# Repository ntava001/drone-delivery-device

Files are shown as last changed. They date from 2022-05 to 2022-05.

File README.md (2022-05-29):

# Drone Delivery Device

A drone delivery device able to obtain and distribute a package for the consumer

## Introduction
One of the biggest problems with a drone delivery system is maneuverability around a crowded residential area. Currently, drones need to land in an open area, but that can be problematic in less spacious areas. Most residences have obstacles such as trees, power lines, and light posts that can impede the drone’s ability to land. Thus, my team and I's design solution for this problem is to build an 18 foot tall system that clears most obstacles, safely catching a package dropped by a hovering drone, without the drone landing, and to transporting the package to a more accessible area for the consumer to pick up.

The Virtual and Physical Prototype of our design operate roughly the same way. The virtual prototype is used to show how our design would look like using a full scale model. It illustrates the design of the device with respect to a house, includes the padding used to catch the package as well as the sensor that detects it. The physical model is very scaled down and dictates how our device will operate in real life. The physical prototype looks more at the electrical components used to drive the motor, allowing us to create the intended design.

## Prototype Demonstrations 

### SolidWorks Prototype

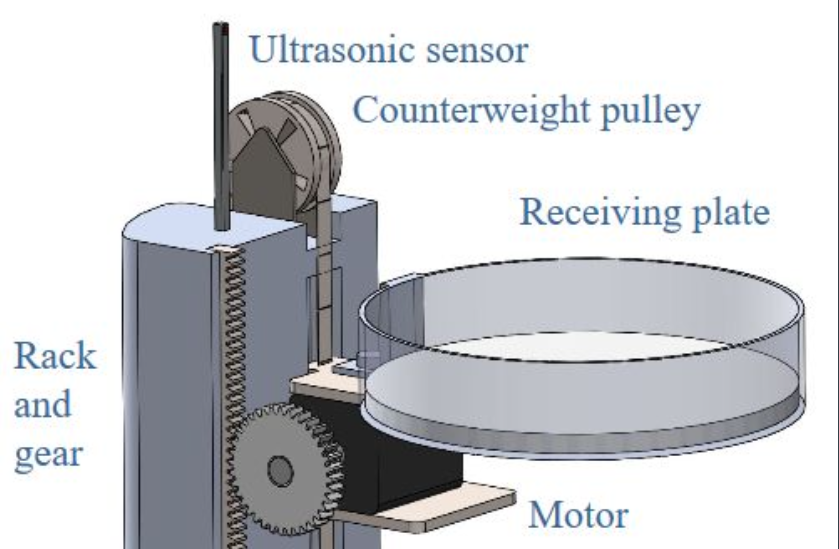
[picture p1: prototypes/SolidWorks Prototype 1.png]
SolidWorks1


### Physical Prototype

Physical1

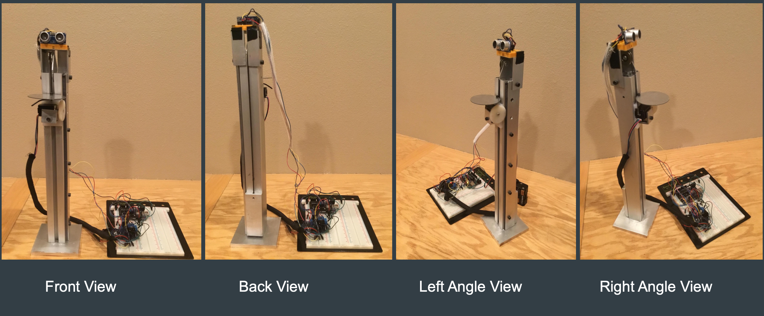
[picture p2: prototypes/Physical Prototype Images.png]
Physical2


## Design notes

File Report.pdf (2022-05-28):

## Team D4S-2 Ara Petrosyan Jason Chan Navid Tavakoulnia Oscar Jauregui

# University of California, Riverside Department of Mechanical Engineering

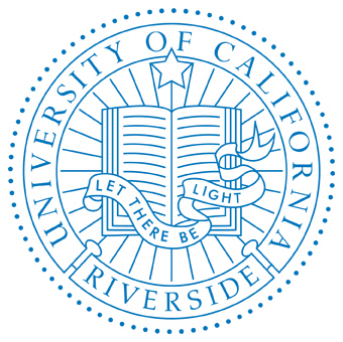
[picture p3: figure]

Executive Summary

With researching and developing a drone delivery system, there are certain limitations and restrictions it

must overcome. One of the biggest problems with a drone delivery system is maneuverability around a crowded

residential area. Currently, drones need to land in an open area, but that can be problematic in less spacious

areas. Most residences have obstacles such as trees, power lines, and light posts that can impede the drone’s

ability to land. Thus, our design solution for this problem is to build an 18 foot tall system that clears most

obstacles, safely catching a package dropped by a hovering drone, without the drone landing, and to

transporting the package to a more accessible area for the consumer to pick up.

Our design solution is to create a receiving platform run by a motor. The theoretical idea for our solution

is to catch the package as it is free falling by accelerating the receiving platform downwards to closely match

the velocity of the falling package. Because of the similar velocities, the package landing on the platform will

impart a very minimal average force due to impulse momentum theory, thus, greatly reducing the chance of any

damage on the package. The key features of our proposed designs include an ultrasonic sensor that will detect

the package, a rack and pinion, a counterweight, the receiving platform with dampening foam, and a T-slotted

frame that will vertically guide the movement of the counterweight and receiving platform.

To evaluate the success or failure of our design solution, we modeled a virtual design using SolidWorks

as well as built and machined a physical prototype. In SolidWorks, we were able to fully simulate real-world

conditions such as the weather, environment, and mechanical properties of materials. In our SolidWorks

simulation, we designed a drone to deliver and drop a package, and our design solution was able to function as

we intended to without any problems. For our physical prototype, we simplified many mechanisms to simply

show a “proof of concept.” We used an Arduino and a stepper motor to simulate the controls aspect of the

design. Common problems that occurred include gear slippage, friction, lack of motor power, and delay in the

sensor. Recommendations for improving this design can stem from better materials, better coding for the

Arduino, a dedicated power supply, and the use of a photo sensor or laser instead of an ultrasonic sensor to

remove the delay in detecting the package.

Table of Contents

1. Introduction -------------------------------------------------------------------------------------------------------------3
2. Problem Statement --------------------------------------------------------------------------------------------------3-4
3. Design Solution --------------------------------------------------------------------------------------------------------4

3.1 Conceptual Design to Detailed Design ----------------------------------------------------------------------4-6

3.2 Design Description ------------------------------------------------------------------------------------------------6

3.3 Functions of Key Features -------------------------------------------------------------------------------------6-7

3.4 Overview of Design----------- ------------------------------------------------------------------------------------7

3.5 Constraints and Assumptions ------------------------------------------------------------------------------------8

3.6 Physical Prototype Design -----------------------------------------------------------------------------------8-10

4. Modeling and Analysis ----------------------------------------------------------------------------------------------11

4.1 Statics -------------------------------------------------------------------------------------------------------------11

4.2 Kinematics and Dynamics -------------------------------------------------------------------------------------12

4.3 Impact Analysis --------------------------------------------------------------------------------------------------12

4.4 Motor Power Requirements ------------------------------------------------------------------------------------13

4.5 Vibration Analysis -----------------------------------------------------------------------------------------------14

5. Approach to Solution ------------------------------------------------------------------------------------------------14

5.1 Morphological Chart --------------------------------------------------------------------------------------------14

5.2 Early Conceptual Designs ----------------------------------------------------------------------------------15-17

5.3 Decision Matrices -------------------------------------------------------------------------------------------18-19

6. Discussion of Results ------------------------------------------------------------------------------------------------20

6.1 Test Procedures and Results -----------------------------------------------------------------------------------21

References -------------------------------------------------------------------------------------------------------22

Appendix ------------------------------------------------------------------------------------------------------23-24

### 1. Introduction

On December 1st, 2016, Jeff Bezos, CEO of Amazon reveals on CBS’ 60 Minutes the idea of using a fleet of

drones to quickly deliver packages to consumers. Ever since Bezos’ public announcement of developing a drone

delivery service, other logistics services and companies decided to do the same. Companies and services such as

United States Postal Service (USPS), FedEx, DHL, UPS, and even 7-Eleven are researching and developing

their own drone deliveries to keep up with technology, and more specifically, Amazon. This new concept

revolves around the idea of utilizing drone technology to transport packages to customers and stands as a

primary inspiration for our project. Many challenges, however, are certain to rise from this method of delivery.

Thus, these challenges stand as a motivation for our intended project. One of the challenges is the means of

properly accepting the delivery upon the arrival. Thus, our problem statement is the means of making a device

that can properly accept packages dropped in free fall from drones. The intended customers for this device are

regular online delivery users who own residential property. This report will begin by presenting the devised

design solution followed by an analysis demonstrating its plausibility, and providing the approach undertaken

for the solution.

### 2. Problem Statement

The drone based delivery system along with basic facts regarding homes in the United States has influenced our

problem definition. The nature of the drone based delivery involves an active drone that would maneuver

around a home to provide delivery. Most homes however, have trees, light posts, gutters, possible power lines

and other obstacles that can potentially be hazardous to the drone itself as it will presumably have to maneuver

around it. The lower the drone would have to go down to the landing spot, the more obstacles it will presumably

encounter. Thus, to provide efficiency, it is best for the drone to remain at higher elevations relative to the

property. Furthermore, environmental factors such as high winds can influence this system. Thus, our problem

definition is to make a device that can receive the package dropped by a drone from a height of 18 feet from

ground level, protect it from theft and environmental factors, and transport it to an intended location for the recipient under the conditions of a maximum wind speed of 5 mph and a drone horizontal velocity of within

2mph.

### 3. Design Solution

### 3.1 Conceptual Design to Detailed Design

The “Top Down Approach” was implemented to break down the main function of our design to several

sub functions. The main functions of our designs consist of the ability to catch a falling load, absorb the impact,

and transport it to a location for pick up. The sub functions for the design include opening of the flaps of the

receiving plate, lifting and lowering of the receiving plate, rotation of pulleys, and providing a light post for

aesthetics. The chosen conceptual design to accomplish these mechanisms is shown in Figure 1.

Figure #1 Conceptual Design of Motor Powered Receiving Tower

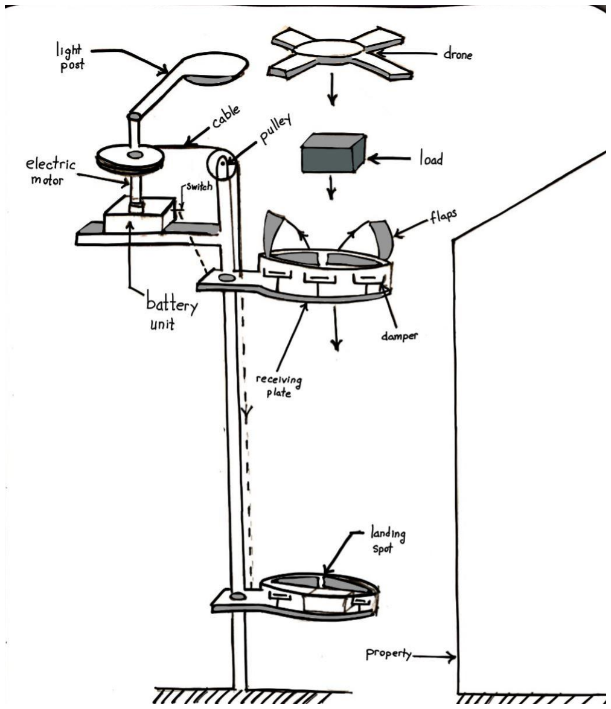
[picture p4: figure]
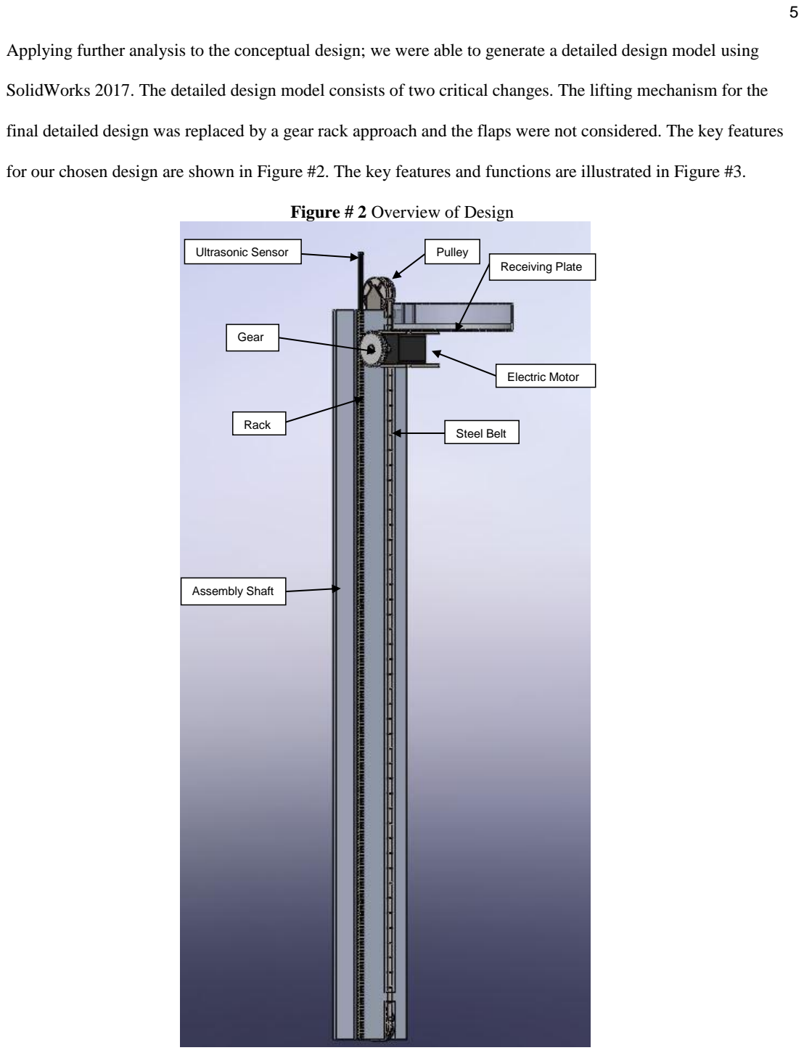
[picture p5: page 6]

Applying further analysis to the conceptual design; we were able to generate a detailed design model using

SolidWorks 2017. The detailed design model consists of two critical changes. The lifting mechanism for the

final detailed design was replaced by a gear rack approach and the flaps were not considered. The key features

for our chosen design are shown in Figure #2. The key features and functions are illustrated in Figure #3.

Figure # 2 Overview of Design

Receiving Plate

Rack

Pulley

Steel Belt

Gear

Ultrasonic Sensor

Assembly Shaft

Electric Motor

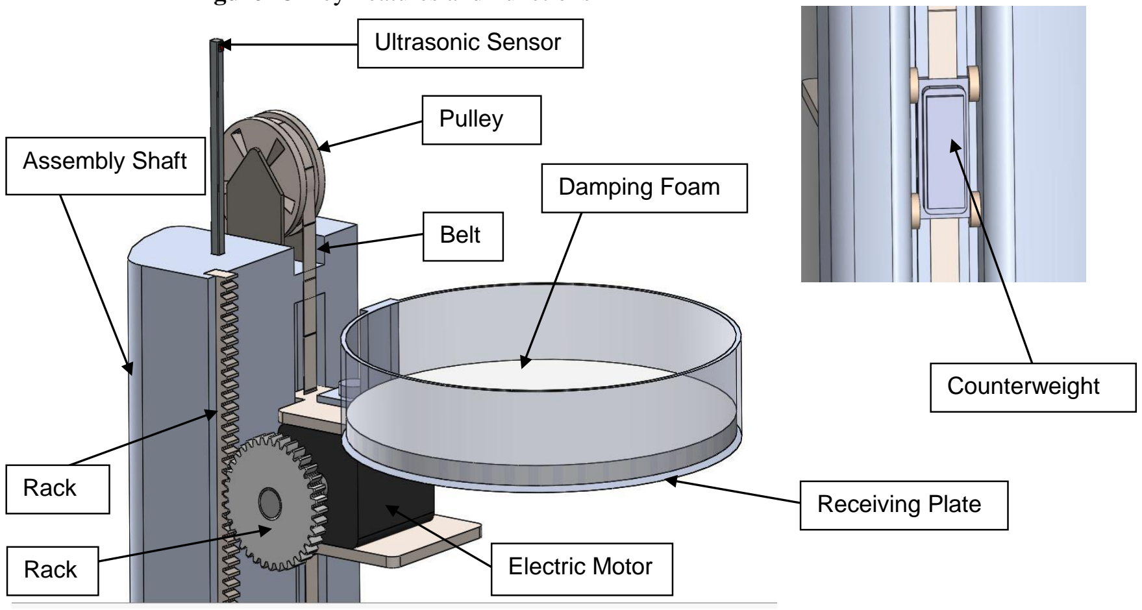
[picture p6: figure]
Pulley; Rack; Assembly Shaft; Ultrasonic Sensor; Damping Foam; Belt; Electric Motor; Receiving Plate; Counterweight

### 3.2 Design Description

As mentioned before, drone deliveries require clearance space from obstacles. Therefore our chosen design

resembles an 18 feet tower shaft. The primary function of our chosen design is to provide a lifting and lowering

mechanism. The receiving plate rides along the main assembly shaft. This feature, as will be described stands

crucial to receiving, protecting, and transporting a package dropped by a drone down to an intended location.

### 3.3 Functions of Key Features

Our chosen design consists of nine main features, each of which has specific function. The ten primary features

include the gear, rack, electric motor, receiving plate, damping foam, continuous belt, an ultrasonic sensor,

pulley and of course the main assembly shaft. The electric motor provides power to the gear which in turn rides

along the rack. Thus, the torque provided by the electric motor allows, the main receiving plate to move up or

down the main assembly shaft. A counterweight rides along the back of the main assembly shaft. The

counterweight and the receiving plate are supported by a continuous belt along top and bottom pulleys. The

purpose of the counterweight is to match the weight of the receiving plate and electric motor, thereby keeping

the system in equilibrium. The receiving plate serves as the target location where the package is intended to

Figure #3 Key Features and Functions

land. It is circular with a diameter of 1 meter. The damping foam, shown in white, sits inside the receiving plate

to soften the falling impact. An ultrasonic sensor sits on top of the main assembly. This provides key electrical

inputs to the motor. A critical theme of our design involves catching the falling mass. This is accomplished with

the ultrasonic sensor and the motor. As the mass passes by the ultrasonic sensor, the receiving plate shall

accelerate downward to a location along the shaft that matches the speed of the falling mass upon contact. Once

it is caught, the receiving plate steadily descends downward to deliver the package.

### 3.4 Overview of Design

The environment for which our design must be compatible with is outdoors near an average residential house as

shown in Figure #3. The graphic illustrations help visualize how are chosen concept will actually blend with its

appropriate environment. What a drone delivery will be expected to look like based off of our design upon the

receiving and transporting end is shown in Figure #5 and Figure #6 respectively.

Figure #4 Overview Design with Environment

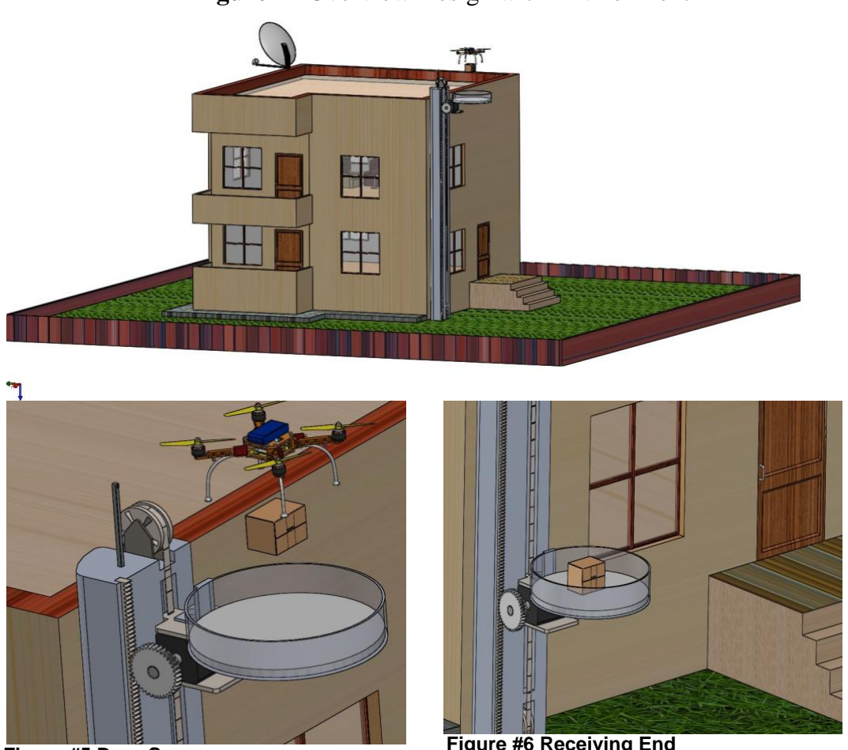
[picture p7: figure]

Figure #5 Drop Scene | Figure #6 Receiving End

### 3.5 Constraints and Assumptions

Several constraints and assumptions are implemented in the design for functionality purposes. The materials

used to construct the components of the device shall be assumed to live up to their physical properties. These

include factors such as the yield and tensile strength. As the drone approaches the target location, it must be at a

maximum height of 5 feet above the center of the receiving plate and have a maximum horizontal velocity of

2.2 mph. Wind conditions may vary, but the maximum allowable wind speed in any arbitrary direction will be

no more than 5 mph. Air resistance within this range shall be designed to be negligible and not affect the

functions of the design. The acceleration due to gravity will be presumed as

With regards to the

load, the minimum weight is constrained to 1 lb with a maximum weight of 50 lbs. Furthermore, the package

dimensions shall not exceed 1 x 1 ft.

### 3.6 Physical Prototype Design

A physical design was machined together to resemble our virtual design. The purpose of a physical prototype is

to create a scaled down representation of the virtual model that can detect the velocity of a falling package and

obtain it with a receiving plate. It is composed of an ultrasonic sensor that is used to detect the falling mass, and

activate a motor to move the object along a rack . The weight of the receiving plate, stepper motor, and slider

are held in place by a counter weight using a pulley system. This allows each of the components to remain

stationary at the top of the assembly shaft when there is no operation taking place. The motor itself is attached

to a gear and held in place by a slider that enables a smooth transition throughout the rack. The rack is attached

to an aluminum strip to keep it immobilized and the receiving plate is pinned to the rod to remain static. We

used a Bipolar motor (20x30mm) operating at 3.9V, since we need a small motor to fit with our rod and one that

can operate with low power.

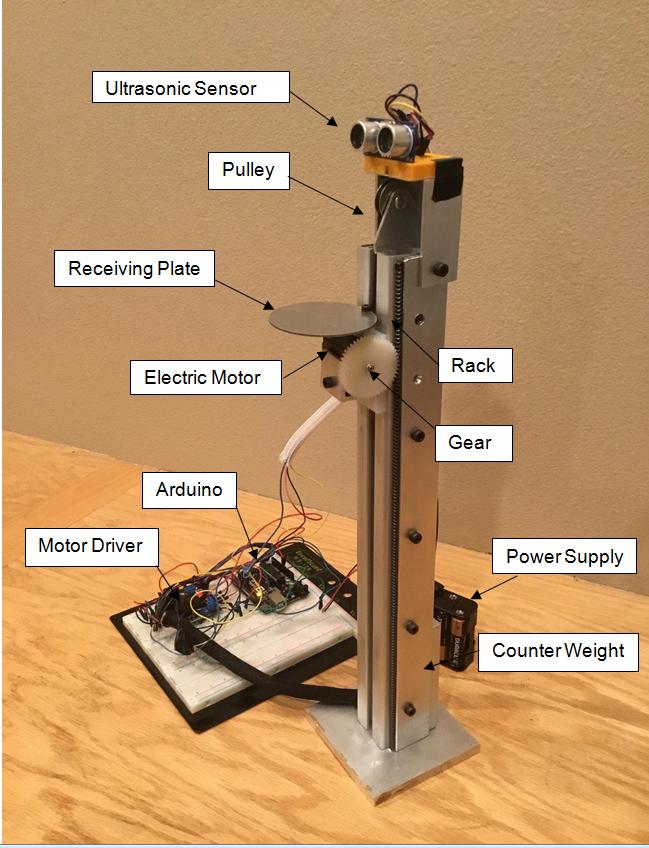
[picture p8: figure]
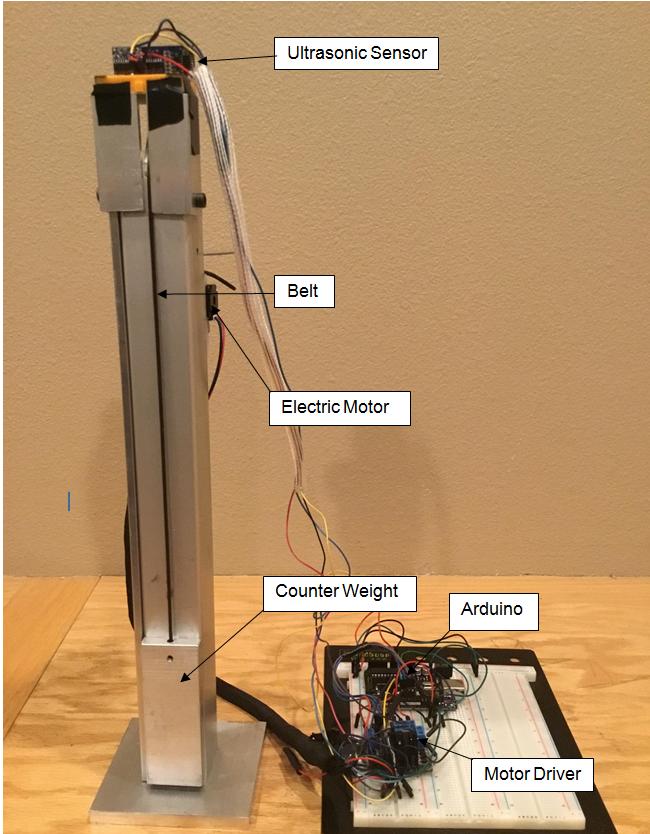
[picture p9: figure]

Figure #7A Physical Prototype-Side View | Figure #7B Physical Prototype- Back View

The electrical components used to operate our motor include an arduino board, motor driver, ultrasonic sensor,

as well as a 9V battery. The code inputted in the arduino allows us to alter the functionality of the motor itself.

We were able manipulate the speed, number of revolutions, direction, as well as the delay time of the motor that

best fits the conditions for our design. The arduino board itself however, provides a low-current control signals

to the motor, so a motor driver is obtained to fix that problem. The motor driver is a little current amplifier

attached to the arduino board to provide higher- current signals that can drive the motor. The ultrasonic sensor

is also attached to the arduino and is the key to starting up all the components. Once the object is detected by

the sensor, the code for the arduino will be read, activating the driver and motor. A 9V battery is attached to the

circuit board as well to provide efficient power to the arduino, ultrasonic sensor, motor driver, and the motor

itself.

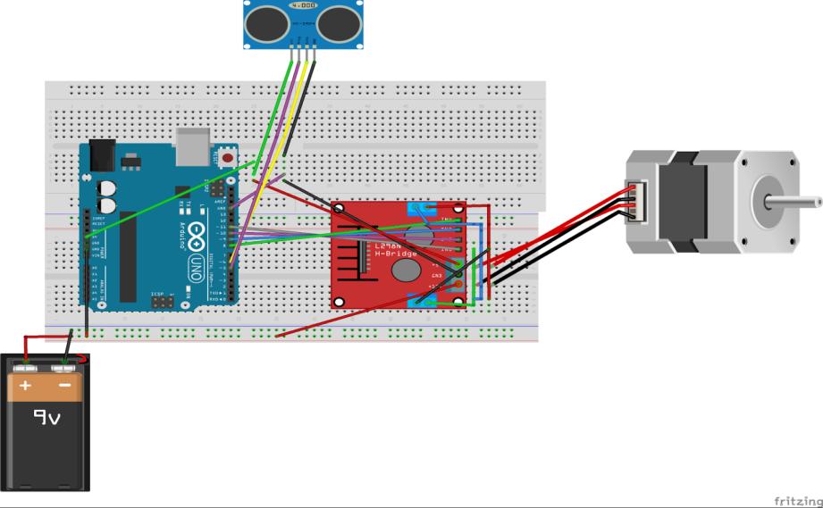
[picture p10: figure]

Figure #9 Electrical Components

The control systems are simplified with the block diagram shown in Figure #9. The load, released by the drone

passes through an ultrasonic sensor. The sensor then sends information related to the package’s velocity at that

instance to the arduino. The arduino then controls the stepper motor by providing it with the necessary steps to

turn in order to match the speed of the falling mass.

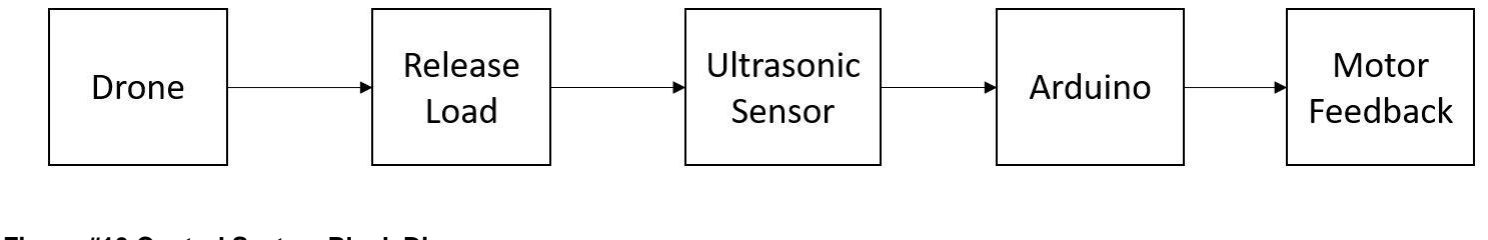
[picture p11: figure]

Figure #10 Control System Block Diagram

### 4. Modeling and Analysis

### 4.1 Statics

Although the chosen motor has enough holding torque, our system must remain in equilibrium at all times such

as in the event of a power outage. A free body diagram for a continuous belt along a two pulley system is shown

below in Figure #9. The sum of moments about point O must be 0 N-m at all times. The weight of our receiving

plate, must therefore, match the counterweight of our assembly. The detailed analysis is shown below.

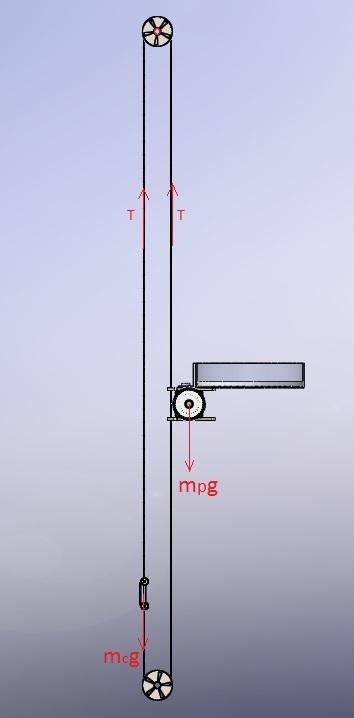
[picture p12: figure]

Figure #9 FBD of pulley system

Estimated Mass of Receiving Plate = 14 lbs (SolidWorks-mass properties)

Tensile Strength of steel cables range from 120-14,000 psi; Thus, with the given weight, steel cables are not expected to yield and the system shall remain in equilibrium at all times.

### 4.2 Kinematics and Dynamics

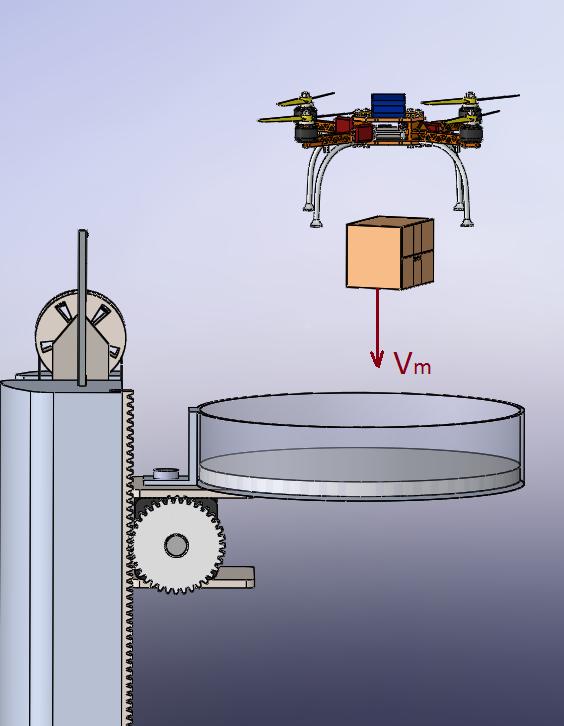
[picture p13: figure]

Figure #10 Falling Mass Scene

Kinematics
As the package is dropped by the drone, energy and

kinematics equations are used to predict the

approximate position and velocity of the falling

mass.

Hence the velocity be slightly less than
The motor should accelerate the plate to attain a velocity of

### 4.3 Impact Analysis

As the mass is released by the drone, the receiving plate is accelerated downward to a point at which its velocity

nearly matches the velocity of the receiving plate. The small difference in velocities results to a minimum

average force exerted by the receiving plate upon contact by impulse momentum theorem.

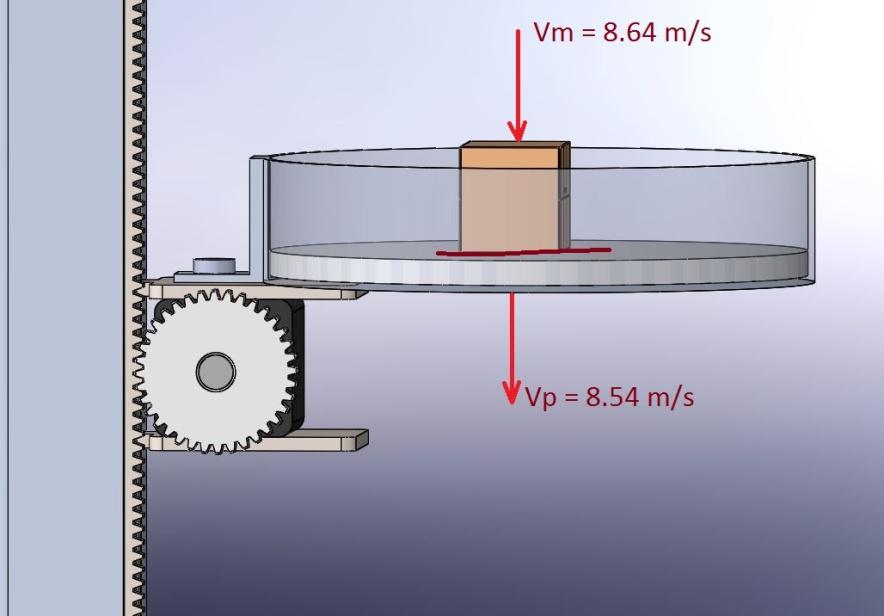
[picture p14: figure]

Figure #11 Impact Analysis

### 4.4 Motor Power Requirements

This goal of this analysis is to calculate the motor power required to accelerate the receiving plate 8.50 m/s at

the same instant at which the mass comes into contact with the plate. The approach used in this analysis

converts the linear model to angular relationships in order to calculate torque and power that the motor must

supply to meet the desired conditions.

Given:

Time elapsed from drop to contact

Necessary linear acceleration of the receiving plate

Thus, a 0.50 horsepower single shafted motor will be necessary for the chosen design.

### 4.5 Vibration Analysis

The impact of the load as it is dropped down to the receiving plate shall be absorbed by polypropylene foam

which will serve as the damper for the system. It is desired to minimize as much vibrations as possible it the

smallest time interval. This corresponds to an overdamped case. Polypropylene foams, which are common in

electrical device packaging, shall be used to dampen the impact of the load.

### 5. Approach to Solution

Various methods to accomplish the key features of our design were organized into a morphological chart as

shown below. Majority of these methods were all considered in out early conceptual designs. A decision

matrix was constructed to decide the most optimal design method upon which the final design was modeled.

### 5.1 Morphological Chart

SOLUTION

| Function
1 | Process Signal | Analog Processor | Microprocessor | Reflective Optical Signal
2 | Absorb Falling Impact | Foam Dampers | Cushion Padding | Styrofoam | Bubble Wrap | Neoprene Pad
3 | Lift or Lower | Pulley | Rack/Pinion | Hydraulic | Chains | Gravity Roller
4 | Provide Power | Electric Motor | Human Power | Battery

### 5.2 Early Conceptual Designs

Design #1 T-Pivot Mechanism | Description: The T-Pivot mechanism as shown above consists of a rectangular plate that pivots about its center. Cables are connected from one end of the receiving plate to a rotating motor powered by a battery. As the package is dropped from state 1 to landing spot at state 2, a natural response activates the motor, causing the receiving plate to rotate onto the 45° inclined beam. At this point the load will slide down with rollers that are mounted along the beam and be stopped by a spring at state 3 for recipient to pick up.

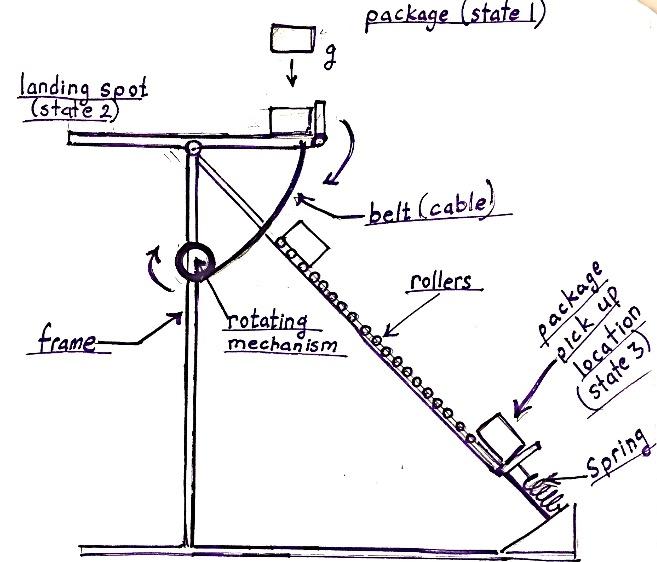
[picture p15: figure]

Design # 2 Roller Guided System | Description:

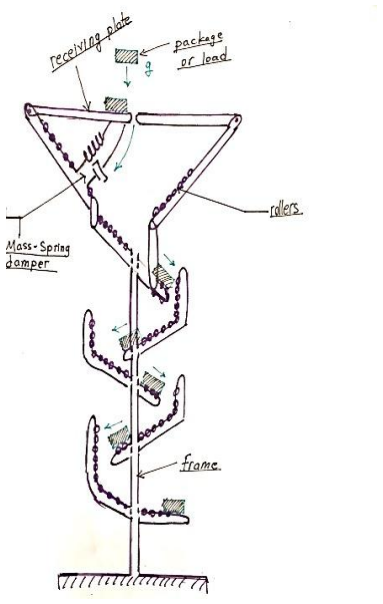
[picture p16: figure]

| This mechanism uses a similar mechanism like design #1. It uses
| a mass-spring damper system to slowly catch the package. The
| package would drop on the receiving plate on either end and the
| mass-spring damper system would safely absorb the energy and
| slowly let down the package into a narrow funnel. The package
| would be guided along using rollers. To transport it from the top
| to the ground level where the consumer can pick up the package,
| a series of angled chutes with rollers on it are placed. The chutes
| and rollers would guide the package down going in a zigzag
| motion until it reaches the ground level.

Design # 3 Rooftop Receiver | Description: | 16

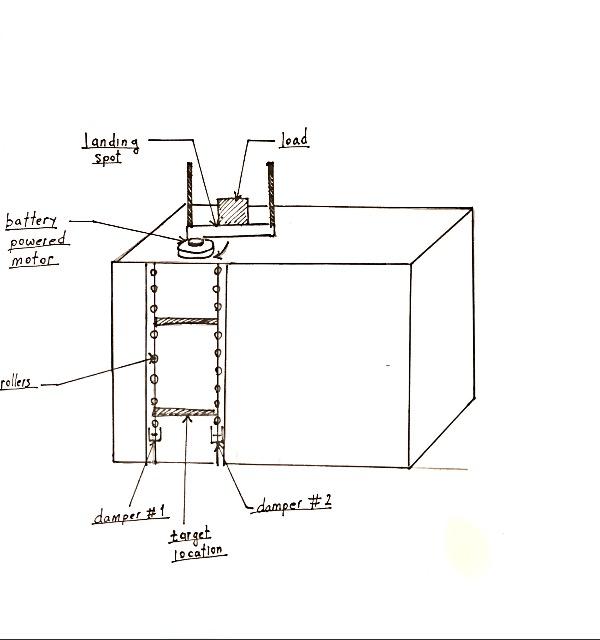
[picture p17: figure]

For the Rooftop Receiver mechanism, the load is dropped

on the property illustrated by a landing stop. The package is

then moved by battery powered motor attached to the top of

the house. From there, rollers are used not only to reduce

friction, so they can maintain a desired motion, but move

the package towards a target location where dampers absorb

| the energy of the load.
Design #4 The Funnel System | Description:

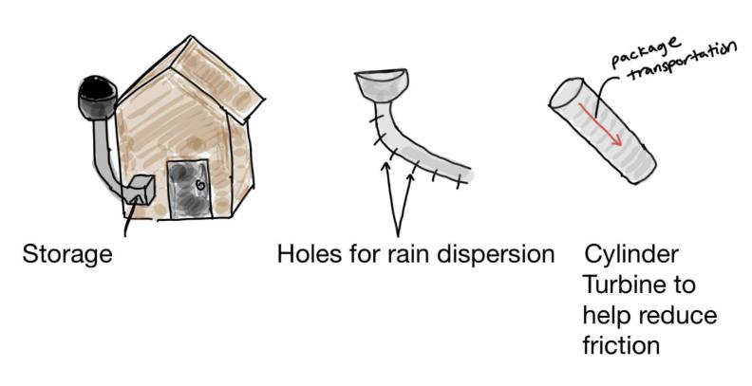
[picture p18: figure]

| The mechanism is attached close to the front door of any
| average American home. At the top is the opening where the
| position is stationary. A pivot lid could be located at the top
| of the opening to help with absorption and allowing the
| package to go straight through for a simple entry. For the
| transportation a cylindrical tubing can be provided to help
| reduce friction as the package slides down to a safe
| container. Possible holes can be inserted along the cylinder to
| help disperse any unwanted particles.

Design # 5 Motor Driven Rack and Pinion | Description

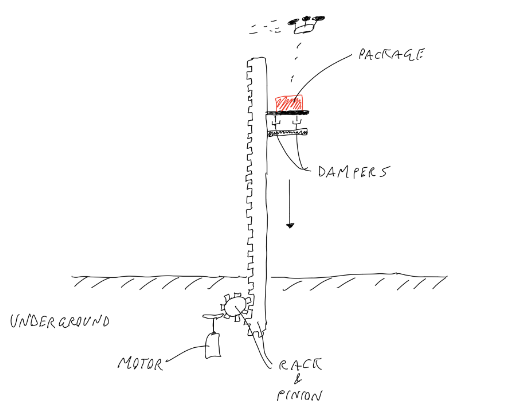
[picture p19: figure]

| In this concept the motor located below ground level
| utilizes the rack and pinion method for elevating the
| delivery tower. At the top of the tower sits the
| receiving plate supported by dampers for absorbing
| the impact.
Design # 6 Elevated stand | Description

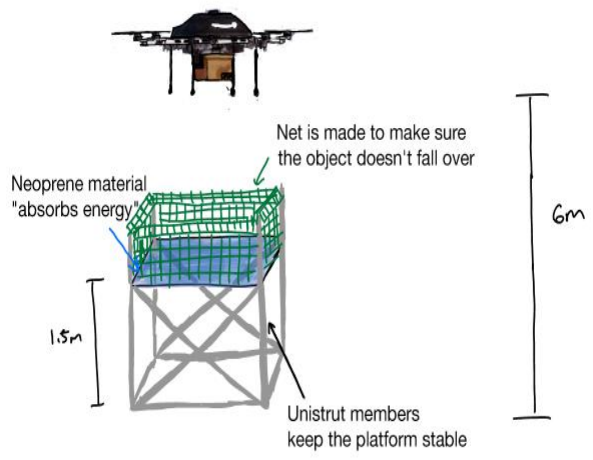
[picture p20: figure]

| When the object is dropped 6 meters high the
| absorbing pad made of neoprene will catch the
| package and a net will be attached to the upper two
| feet of the platform to prevent the package from
| dropping on the ground. This design will allow for
| any package up to 24 kilograms to land safety one
| and a half meters. The Neoprene pad is to be
| designed so it withstands any kinetic or potential

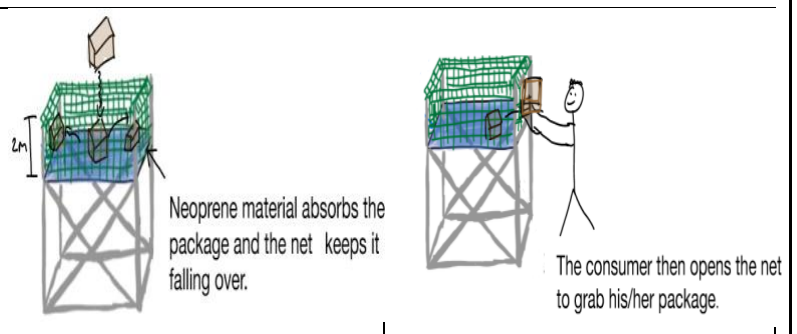
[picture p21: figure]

| energy produced from dropping the package. The net
| is a protection at the boundary of the Neoprene pad to
| prevent the box from falling into the ground. To grab
| the package the consumer will just need to open the
| net that is located 1.5 meters from the ground.

### 5.3 Decision Matrices

Absorbing Impact

| Criteria | Weight | Foam Dampers | Cushion Padding | Styrofoam | Polypropylene Pad
| | | | S | S | +
2 | cost | 4 | | S | + | -
3 | aesthetics | 2 | | S | - | +
4 | noise produced | 5 | | + | S | +
5 | reliability | 9 | | + | S | +
6 | durability | 7 | | S | S | +
7 | easy to replace | 6 | | S | S | -
8 | tolerance | 3 | | S | S | S
9 | sustainability | 8 | | S | S | +
10 | visibility | 1 | | S | S | S
| Total | | | +2 | 0 | +6
| Weighted Total | | | +16 | +2 | +37
1 | safety | 10 | D A T U M

Lifting and Lowering Mechanism

| Criteria | Importance | Cable/Pulley | Rack and Gear | Chain | Gravity Roller
| | | | + | - | +
2 | safety | 10 | | + | - | -
3 | aesthetics | 3 | | + | S | +
4 | maintainability | 2 | | S | S | +
5 | range of motion | 4 | | S | S | -
6 | reliability | 9 | | S | S | S
7 | smoothness | 8 | | + | - | S
8 | noise level | 5 | | + | - | +
9 | easy to operate | 6 | | + | S | +
10 | tolerance | 1 | | S | S | -
| Total | | | +6 | -5 | +2
| Weighted Total | | | +39 | -34 | +8
1 | speed | 7 | D A T U M

### 6. Discussion of Results: Evaluation of Your Design

The Virtual and Physical Prototype of our design operate roughly the same way. The virtual prototype is

used to show how our design would look like using a full scale model. It illustrates the design of the device with

respect to a house, includes the padding used to catch the package as well as the sensor that detects it. The

physical model is very scaled down and dictates how our device will operate in real life. The physical prototype

looks more at the electrical components used to drive the motor, allowing us to create the intended design.

Thus, it is to demonstrate the controls of our design as proof of concept.

One of the strengths for our design was the ability to control a stepper motor. We were able to make sure

our motor matched the velocity of the falling package through arduino code. Therefore, we had little to no

problems when it comes to implementing the correct velocity for the motor so no damage would come to the

package. Strength for our design was the simulation for the virtual prototype. From our virtual we were able to

notice from the start what changes needed to be done for our design before machining. It gave us a scope for

what was possible when creating the best physical prototype in the time we had to make it. SolidWorks

simulation was very beneficial in that it provided a blueprint for what we were trying to achieve with the

physical.

Weakness came from the physical prototype for our design. Friction build up of the gear/rack when

running the motor was one of the biggest problems we had. The motor would often get caught up with the gear

and remain stationary. Another problem was the slippage of the gear along the rack. There were times when the

gear would move along the rack to fast, so we had to provide more counter weight to prevent it from slipping.

The amount of power needed to run the arduino, driver, motor, and ultrasonic sensor was sometimes short. We

noticed that another 9V battery was to be applied in our system as well as a second arduino board for the

ultrasonic sensor. This would allow for more efficient power to be distributed throughout the circuit. There was

also a delay on the ultrasonic sensor which made it difficult to have our motor automatically run when an object

passed through the sensor.

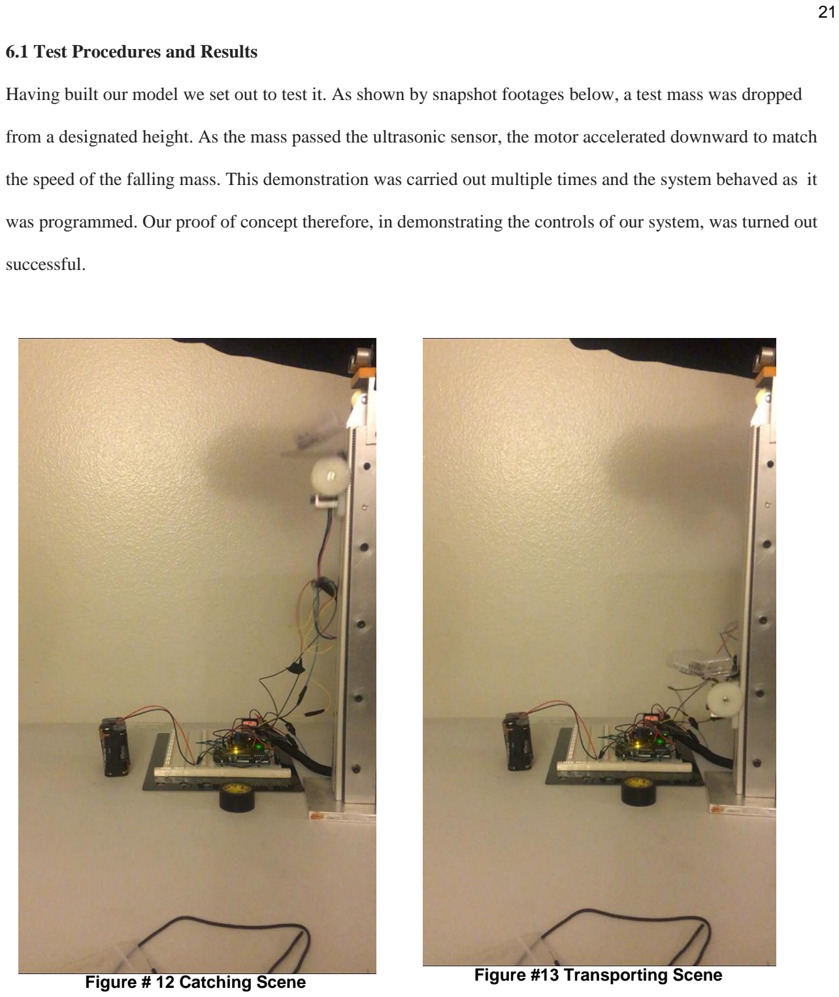
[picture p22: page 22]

### 6.1 Test Procedures and Results

Having built our model we set out to test it. As shown by snapshot footages below, a test mass was dropped

from a designated height. As the mass passed the ultrasonic sensor, the motor accelerated downward to match

the speed of the falling mass. This demonstration was carried out multiple times and the system behaved as it

was programmed. Our proof of concept therefore, in demonstrating the controls of our system, was turned out

successful.

Figure # 12 Catching Scene | Figure #13 Transporting Scene

References

[1] S. S. Rao, Mechanical vibrations. Upper Saddle River, NJ: Pearson Prentice Hall, 2004.
[2] R. C. Hibbeler, Engineering mechanics: dynamics. Upper Saddle River, NJ: Prentice Hall, 2010.
[3] L. Tatham, “Choosing the right extension ladder,” Browns Ladders, 27-Sep-2016. [Online]. Available:

https://www.brownsladders.co.uk/blog/choosing-the-right-extension-ladder/. [Accessed: 15-Dec-2017].

Appendix

[1] R. C. Hibbeler, Engineering mechanics: dynamics.
[2] S. S. Rao, Mechanical vibrations.

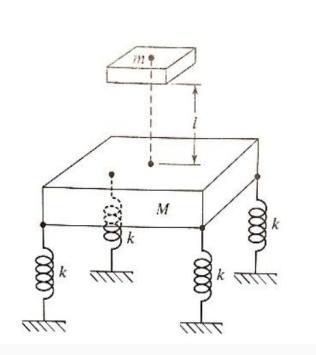
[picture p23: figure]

[4] Sketch 1 2D Schematic

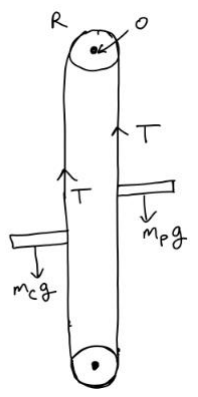
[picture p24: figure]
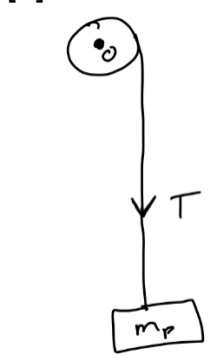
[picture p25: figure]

[5] Sketch 2 Free body diagram of chain-sprocket

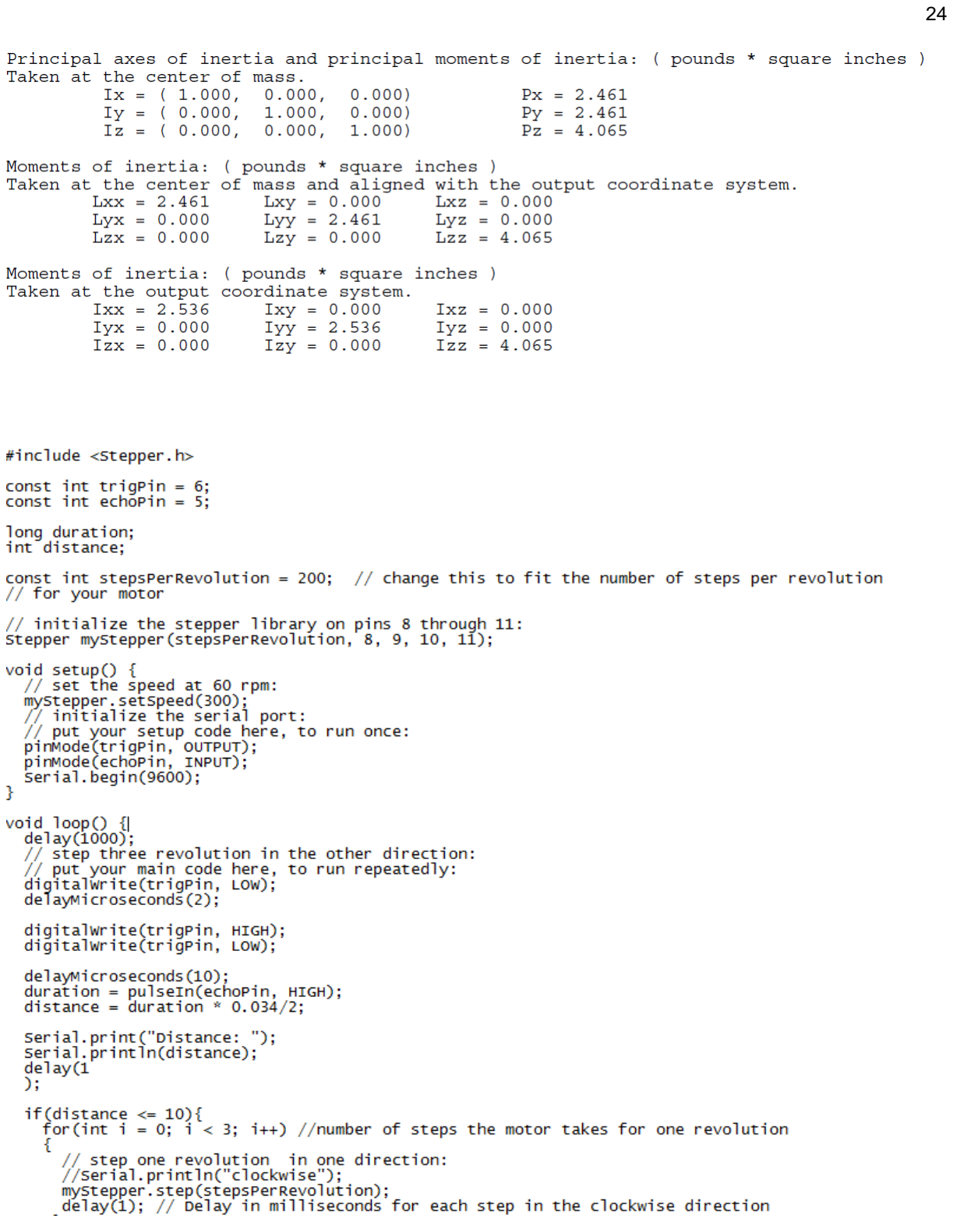
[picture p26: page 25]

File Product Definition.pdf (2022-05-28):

To the Future: Our Solution; Receiving plate; Ultrasonic sensor; Counterweight pulley; Rack and gear; Motor; Side view; Top down view

## Design Requirements:

To apply for Amazon Air Prime, Amazon specifies the package must weigh no more than 5 lbs (2.25 kg), and be small enough to fit into a cargo box that the drone can carry. To not limit our design to just Amazon’s specifications, we broaden our requirements to fill a broader range of possible package sizes and weight.

More specifically, the potential design solution must be able to:
- Catch the package with a maximum weight of 50 lbs without any damage.
- Catch the package within a drone horizontal velocity of 2 mph.
- Catch the package from a 5 foot drop to the 18 foot system.
- Withstand environment factors such as a 20 mph wind.

# RECEIVING STATION FOR DRONE DELIVERY

# Team D4S-2: Design for Sustainability Ara Petrosyan, Jason Chan, Navid Tavakoulnia, Oscar Jauregui University of California, Riverside: Mechanical Engineering

## Receiving Station for Drone Delivery: But Why?

On December 1, 2013. Amazon, the undisputed king of E-commerce and Internet retail made a statement. Jeff Bezos, CEO of Amazon, looks to the future. On CBS 60 Minutes, Bezo introduces to the world the concept of utilizing drones to deliver packages, or Amazon Air Prime; instead of a courier, a fleet of drones would fly to a customer’s residence, and deliver a package within the hour with certain restrictions. With Bezo’s announcement, the entire market for logistics changed. Many other companies such as USPS, FedEx, UPS, and even 7-Eleven are trying to enter the drone delivery market in the near future.


## Tackling the Problem

A typical drone delivery requires it to land in an open area. This is because most homes have trees, light posts, power lines and other obstacles that can restrict the maneuverability of the drone and can also potentially be hazardous to it. To expedite this process, we tackle the problem of delivering and receiving.

Our solution: the drone hovers at a higher elevation relative to the system to avoid obstacles and drops the package so it doesn’t have to land.

The potential design must be able to:

### 1. Safely catch/receive a package dropped from a

hovering drone.

### 2. Protect the package from theft and the

environment

### 3. Transport the package to an area for the

consumer where he/she can easily retrieve it.

## Did it work? Verifying the design

### 1. SolidWorks Simulation

Using SolidWorks to build a virtual model including all features. Animations worked synchronously with the simulation. Simulation was able to bring real-world physics and mechanics, and simulate our model as if we built a full-scale one. We can definitively say that our design meets the requirements set.

2. 1:10 scaled physical prototype Minimizing any complicated mechanism to just show a “proof of concept.” We required the stepper motor to accelerate at 1067 rad/s

2
for 0.25 seconds to match the acceleration and velocity of the falling package, which we could not do because of inadequate power. Other problems such as rack/pinion friction, stepper motor and gear slippage.

## Recommendations and/or Improvements

- Use of low weight material such as aluminum 6061 or special alloy blend with low friction and high heat resistance for greater mechanical reliability
- Model is designed for a 2 story building, 18 feet. To improve marketing, we recommend to scale a model down to 10 feet to accommodate those who live in single story homes.
- Combining receiving station with modern day cluster unit mailboxes. One receiving station can service multiple mailboxes. The system would receive each package, and allocate it to the right consumer’s mailbox and hold it for protection. Cheaper than having one system per house.

## Conceptual Design and Selection


Top-down approach to
break down the main
functions into subfunctions.
- Use of morphological
chart to produce several
viable designs using
different mechanisms to
catch the package.
- Decision matrices used
to assign each criteria a
score of 1-10 and then
tabulating each design
for total points.
- The receiving plate is accelerated downward to nearly match the velocity of the falling package. The small difference in velocities result in a minimal average force of impact upon contact by impulse momentum theorem. Designed to protect and minimize the damage on the package
- Use of an ultrasonic sensor to detect when the package is dropping, triggering the motor to accelerate the receiving plate downward.

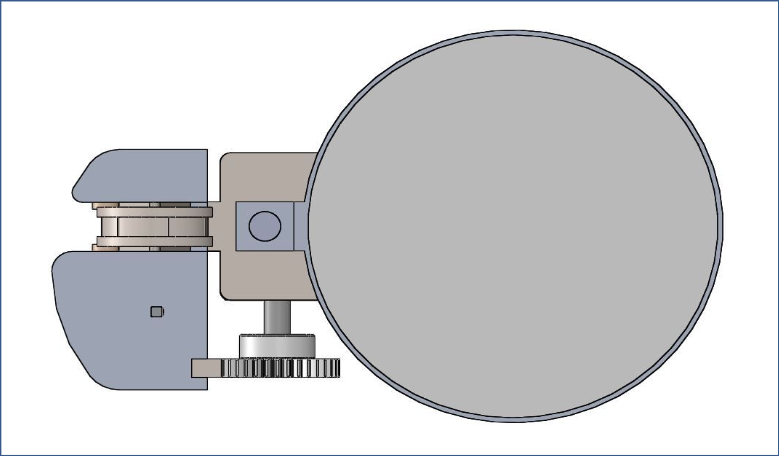
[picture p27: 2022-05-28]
prototypes/SolidWorks Prototype 2.png

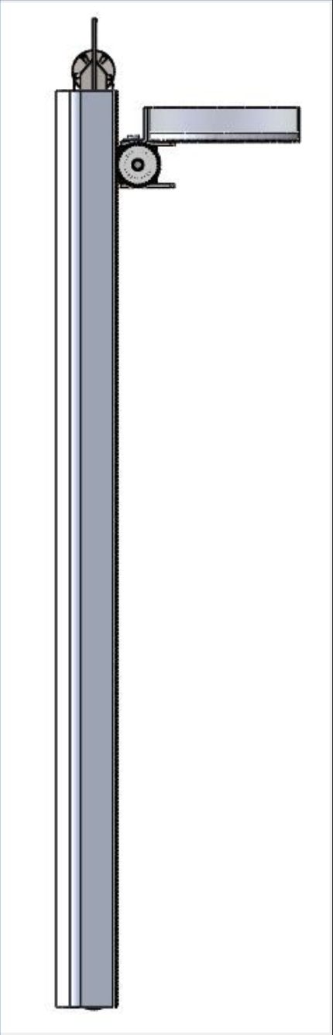
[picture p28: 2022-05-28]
prototypes/SolidWorks Prototype 3.png

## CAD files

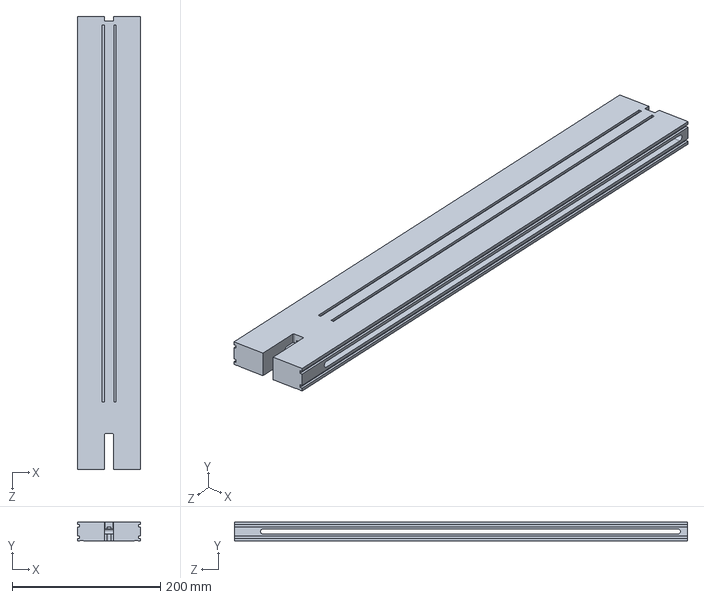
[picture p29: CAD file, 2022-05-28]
models/assembly shaft.SLDPRT
84.3 x 25.4 x 610.9 mm

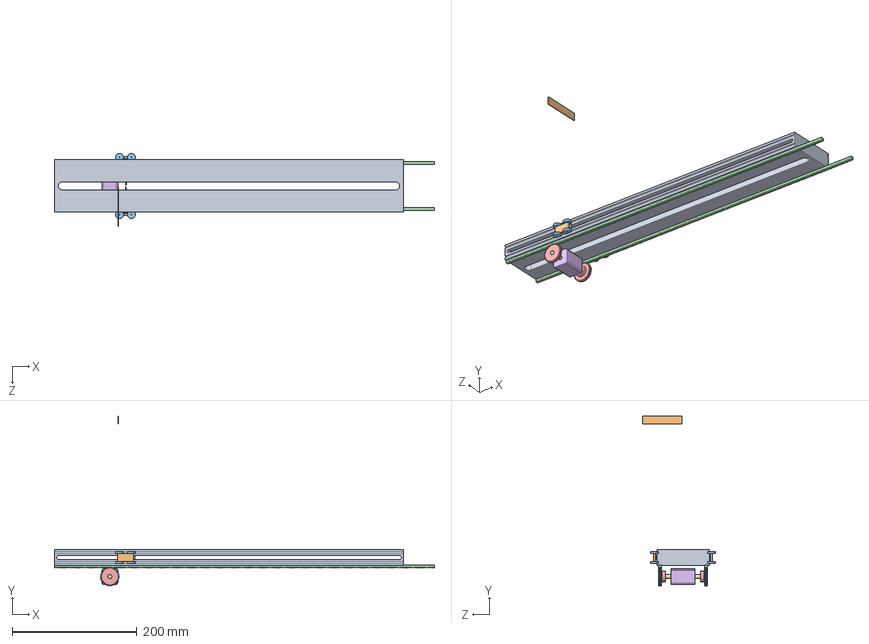
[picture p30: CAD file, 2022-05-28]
models/Design Project - Copy.SLDASM
609.6 x 272.5 x 117.6 mm
roller base x 2
roller wheels x 8
7854K130_HT-LOAD MTL GEAR RACK--20 DEG PRESSURE ANGLE x 2
7880K340_HT-LOAD MTL GEAR--20 DEG PRESSURE ANGLE x 2
stepper motor
motor shaft x 2
roller cage piece x 2
roller cage shorter piece x 2
battery plate bottom

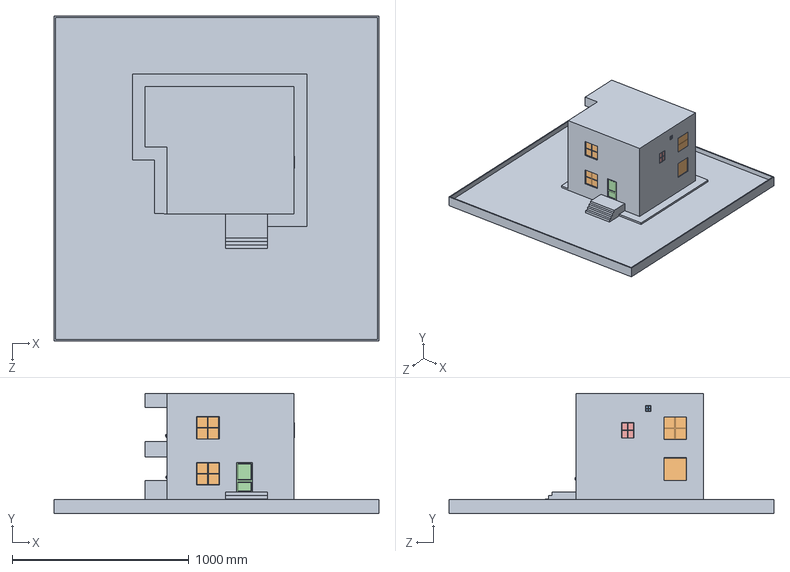
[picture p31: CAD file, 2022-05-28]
models/Assem1.SLDASM
1840.0 x 680.0 x 1840.0 mm
Glass x 11
Small Glass
door2 x 3
med glass

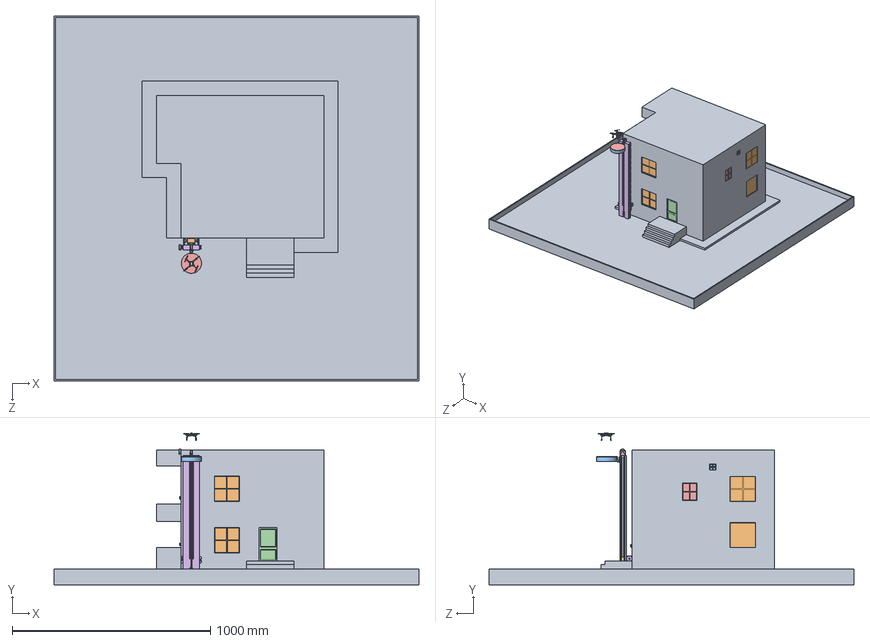
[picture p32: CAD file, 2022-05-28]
models/Design Project with House.SLDASM
1840.0 x 765.9 x 1840.0 mm
Glass x 11
Small Glass
door2 x 3
med glass
assembly shaft
roller base x 3
roller wheels x 12
7854K130_HT-LOAD MTL GEAR RACK--20 DEG PRESSURE ANGLE x 2
stepper motor
motor shaft x 2
pulley x 2
pulley holder x 4
7880K340_HT-LOAD MTL GEAR--20 DEG PRESSURE ANGLE x 2
belt chain part x 100
battery plate
roller cage piece x 2
plate holding piece
Receiving Plate
damper
lid
Cardboard Box
Final Quadcopter assembly

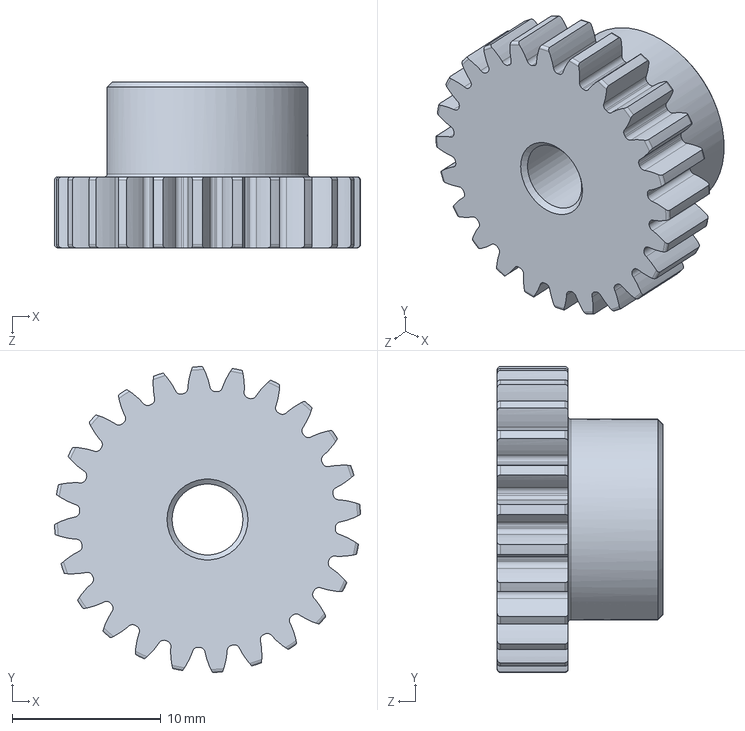
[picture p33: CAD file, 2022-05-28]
models/Gear 7880K31.SLDPRT
20.6 x 20.6 x 11.1 mm

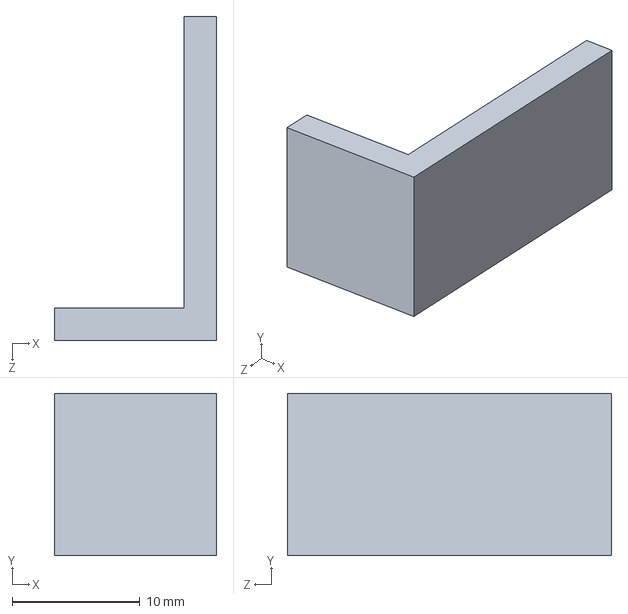
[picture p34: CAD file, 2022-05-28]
models/plate holding piece.SLDPRT
12.7 x 12.7 x 25.4 mm

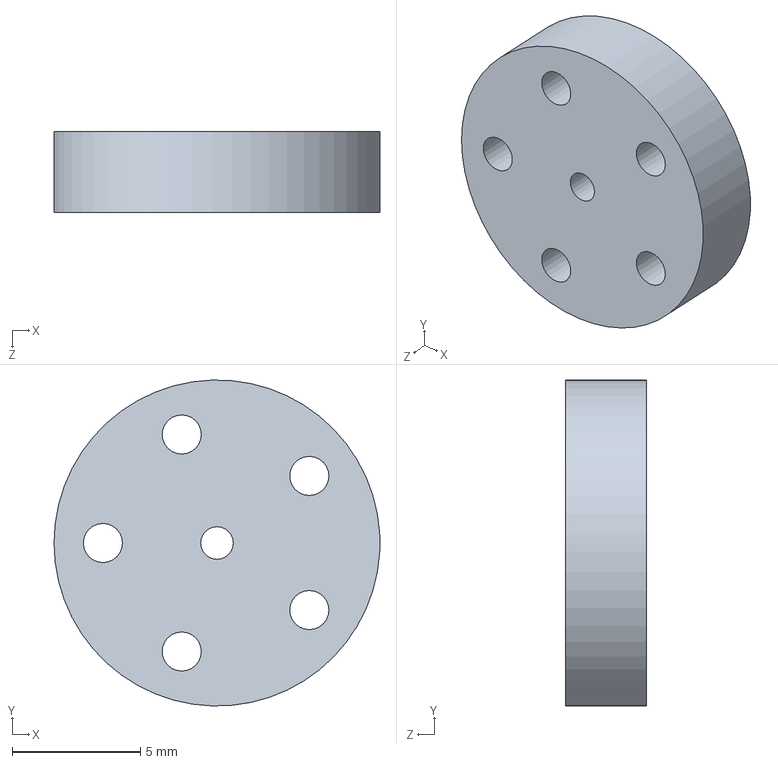
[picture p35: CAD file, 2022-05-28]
models/roller wheels.SLDPRT
12.7 x 12.7 x 3.17 mm

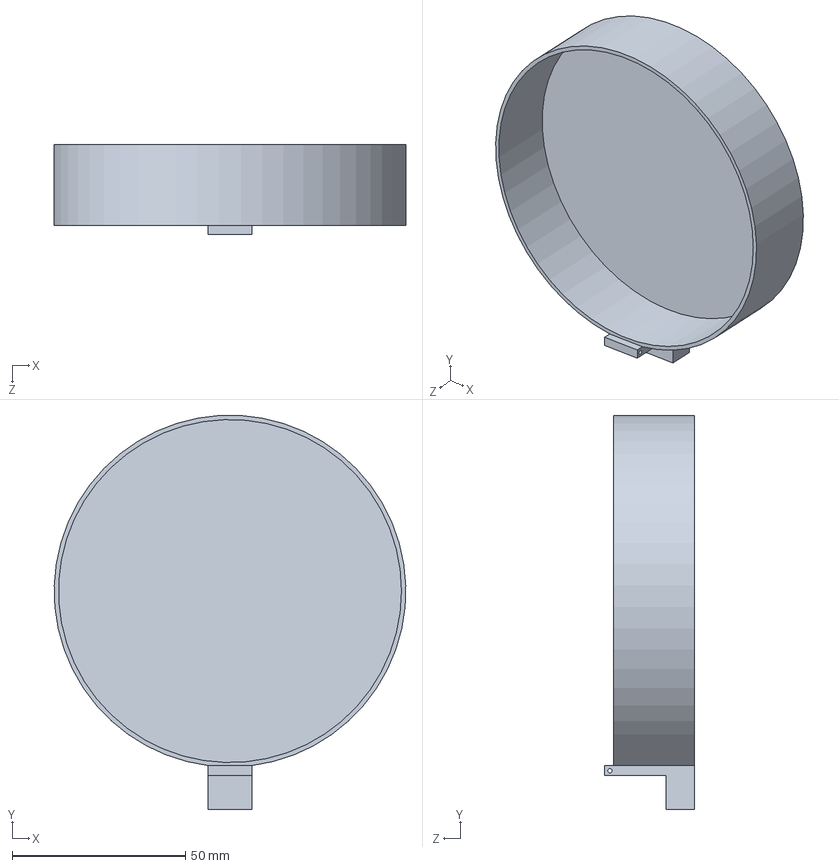
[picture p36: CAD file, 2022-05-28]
models/Receiving Plate.SLDPRT
101.5 x 113.8 x 25.9 mm

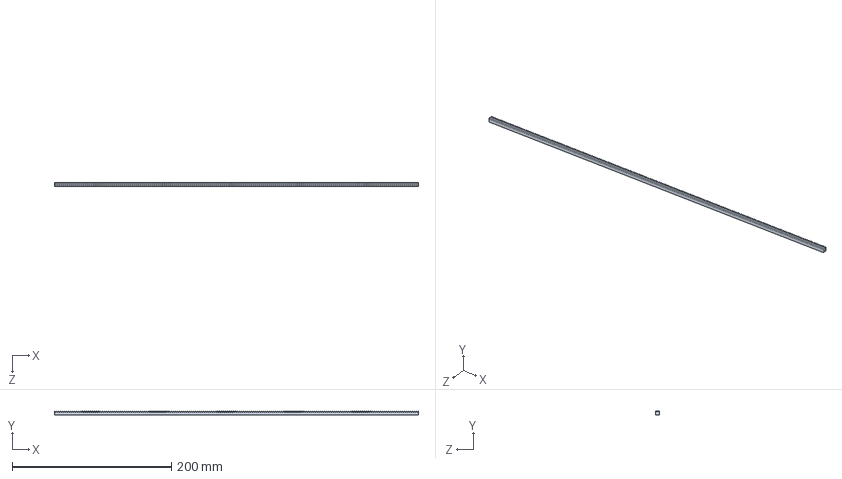
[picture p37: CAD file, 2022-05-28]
models/Rack 7854K13.SLDPRT
457.2 x 4.78 x 4.76 mm

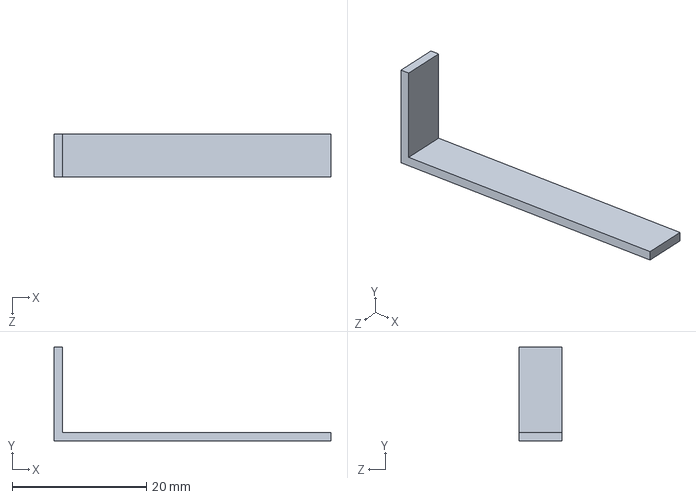
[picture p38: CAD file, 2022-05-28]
models/roller cage shorter piece.SLDPRT
41.3 x 14.0 x 6.35 mm

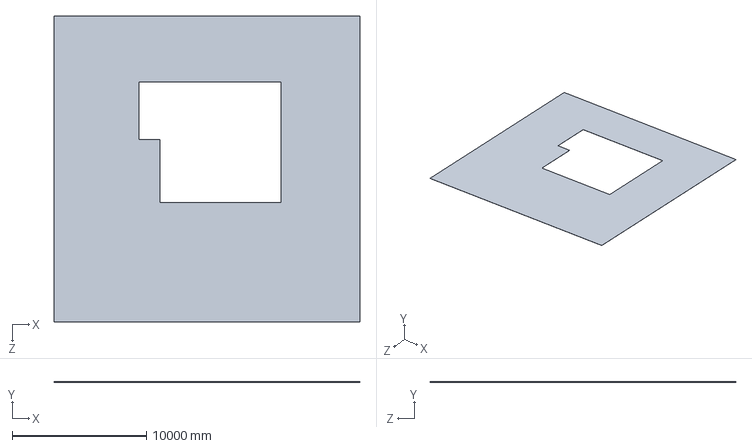
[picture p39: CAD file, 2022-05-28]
models/Part1.SLDPRT
22800.0 x 10.0 x 22800.0 mm

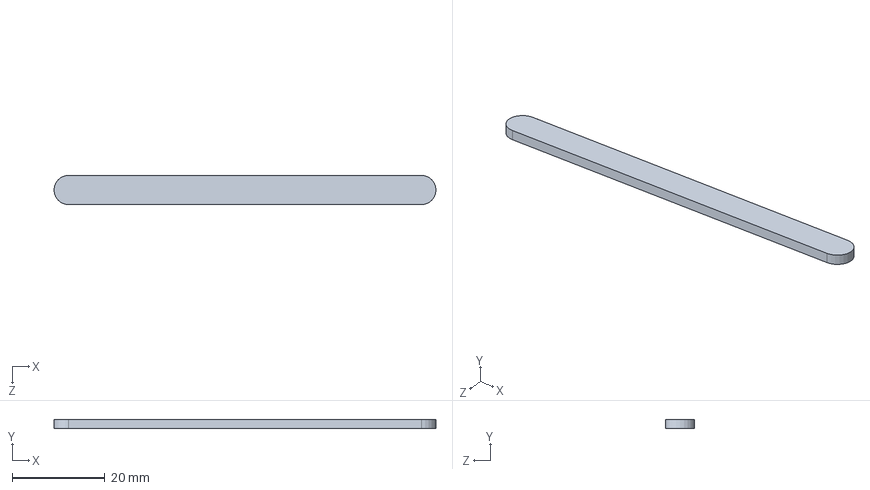
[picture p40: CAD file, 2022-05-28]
models/battery holder.SLDPRT
82.6 x 2.03 x 6.35 mm

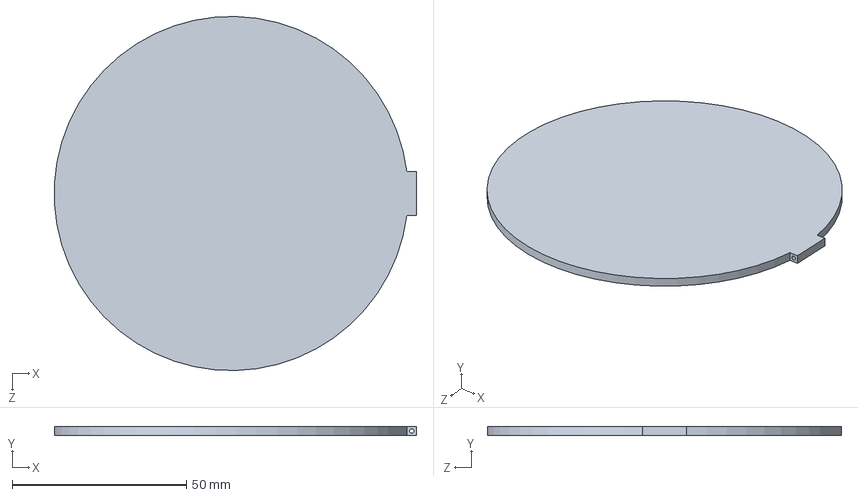
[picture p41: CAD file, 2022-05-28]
models/lid.SLDPRT
103.9 x 2.54 x 101.6 mm

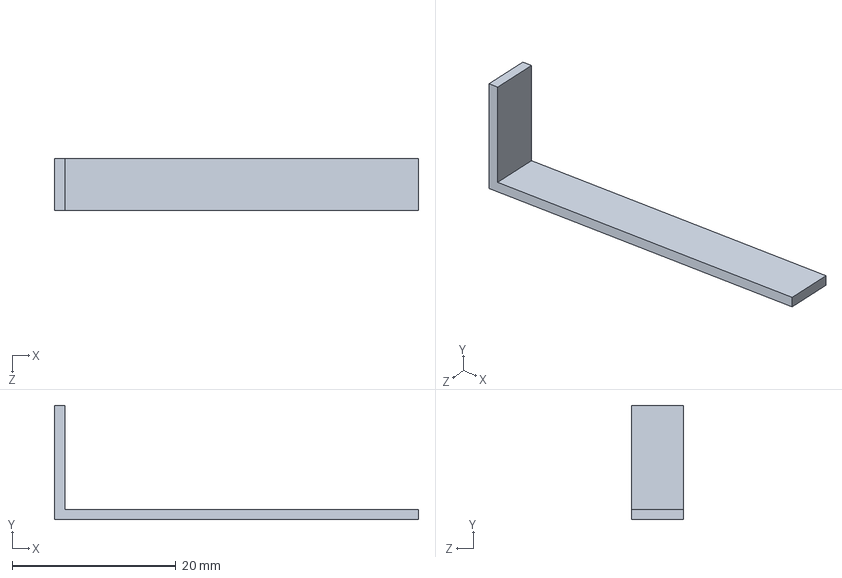
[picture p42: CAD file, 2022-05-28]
models/roller cage piece.SLDPRT
44.5 x 14.0 x 6.35 mm

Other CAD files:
models/Part3.SLDPRT
models/roller base.SLDPRT
models/belt chain part.SLDPRT
models/holder vertical shaft.SLDPRT
models/7854K130_HT-LOAD MTL GEAR RACK--20 DEG PRESSURE ANGLE.SLDPRT
models/7880K340_HT-LOAD MTL GEAR--20 DEG PRESSURE ANGLE.SLDPRT
models/Cardboard Box.SLDPRT
models/Glass.SLDPRT
models/Part2.SLDPRT
models/Small Glass.SLDPRT
models/battery cage.SLDPRT
models/battery plate bottom.SLDPRT
models/battery plate.SLDPRT
models/damper.SLDPRT
models/door2.SLDPRT
models/m2.SLDPRT
models/med glass.SLDPRT
models/medium Glass.SLDPRT
models/motor shaft.SLDPRT
models/pulley holder.SLDPRT
models/pulley.SLDPRT
models/roller cage piece - Copy.SLDPRT
models/roller slide.SLDPRT
models/stepper motor.SLDPRT

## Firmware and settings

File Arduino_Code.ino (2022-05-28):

#include <Stepper.h>

const int trigPin = 6;
const int echoPin = 5;

long duration;
int distance;

const int stepsPerRevolution = 200; // Change this to fit the number steps per revolution for motor

// initialize the stepper library on pins 8 through 11:
Stepper myStepper(stepsPerRevolution, 8, 9, 10, 11);

void setup( ) {
    // set the speed at 60rpm:
    myStepper.setSpeed(300);
    // initialize the serial port:
    // put your setup code here, to run once:
    pinMode(trigPin, OUTPUT);
    pinMode(echoPin, INPUT);
    Serial.begin(9600);
}

void loop() {
    delay(1000);
    // step three revolution in the ohter direction:
    // put your main code here, to run repeatedly:
    digitalWrite(trigPin, LOW);
    delayMicroseconds(2);

    digitalWrite(trigPin, HIGH);
    digitalWrite(trigPin, LOW);

    delayMicroseconds(10);
    duration = pulseIn(echoPin, HIGH);
    distance = duration* 0.034/2; 

    Serial.print("Distance: ");
    Serial.println(distance);
    delay(1);


if(distance <=10)
    for (int i =0; i<3; i++) // number of steps the motor takes for one revolution
    
    // step one revolution in one direction:
    // Serial.printIn("clockwise");
    myStepper.step(stepsPerRevolution);
    delay(1); } //Delay in milliseconds for each step in the clockwise direction
    

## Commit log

2022-05-28 Update SolidWorks
    Added SolidWorks Files
    [7854K130_HT-LOAD MTL GEAR RACK--20 DEG PRESSURE ANGLE.SLDPRT, 7880K340_HT-LOAD MTL GEAR--20 DEG PRESSURE ANGLE.SLDPRT, Assem1.SLDASM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]
2022-05-29 updated prototypes
